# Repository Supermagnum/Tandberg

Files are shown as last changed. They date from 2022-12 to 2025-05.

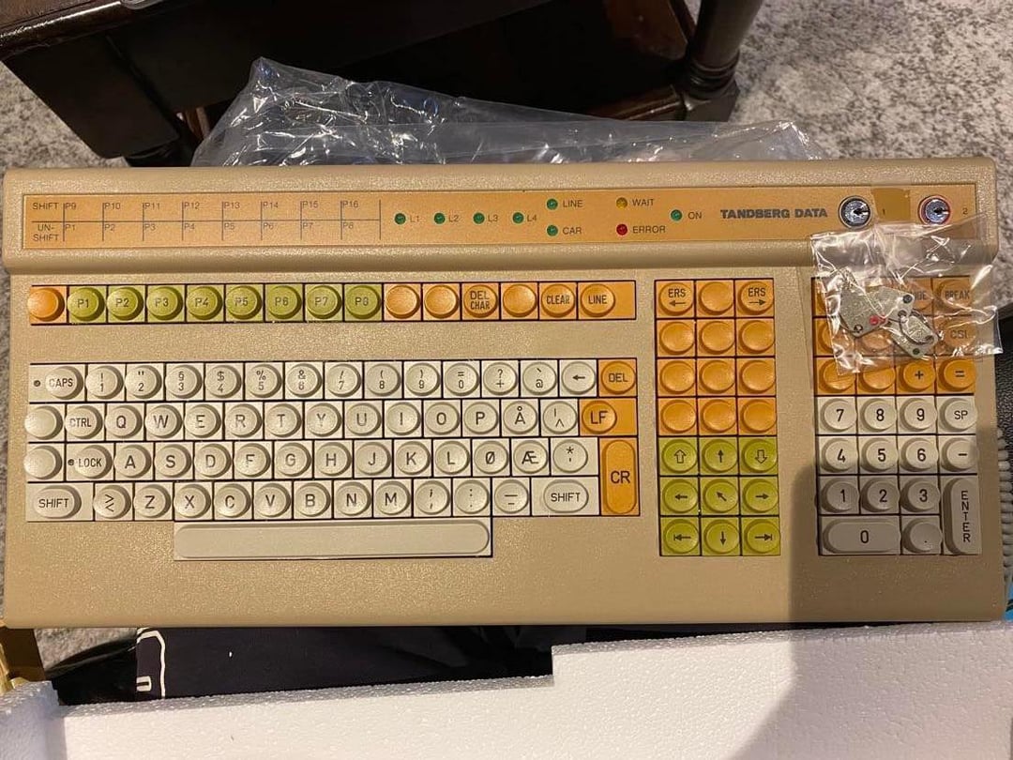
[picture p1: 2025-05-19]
a-tandberg-data-tdv2200-keyboard-picture-from-v0-ows3616kpe4a1-4209977600.jpg

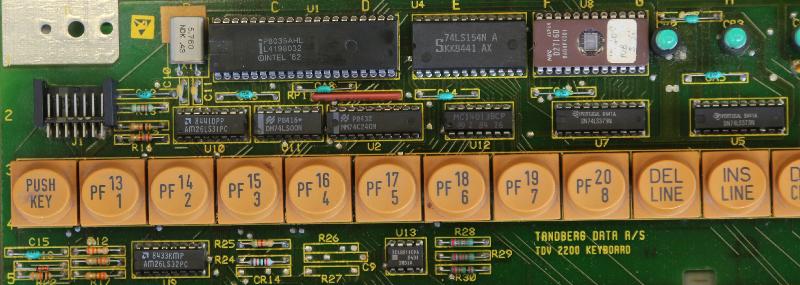
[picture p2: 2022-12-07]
TDV-2200/ROM-Files/TDV-2200 Keyboard Unk1/IMG_9250r.jpg

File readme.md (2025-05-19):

A repository for Tandberg Data Keyboards technical information an ROM's.

It was used for:
https://en.wikipedia.org/wiki/TDV_2200

Picture of a TDV 2200 keyboard:
https://raw.githubusercontent.com/Supermagnum/Tandberg/refs/heads/main/a-tandberg-data-tdv2200-keyboard-picture-from-v0-ows3616kpe4a1-4209977600.jpg

The keycaps looks like Devlin Z series.
https://www.devlin.co.uk/products/components/keycaps.html

They actually are Siemens STB 11/21.
The swtitches are described here:

Early models:
https://deskthority.net/wiki/Siemens_STB_11

Later:
https://deskthority.net/wiki/Siemens_STB_21

Tech details that I have been told: 
The keyboard runs standard UART over RS-485, 2400 baud from the keyboard and 600 baud to the keyboard. This is worth noting, as one does not always expect the speed of Rx and Tx to be different. Bytes sent from the keyboard are mostly pure ASCII codes when regular buttons are pressed.

Other keys have codes with bit 7 set to 1, often with the bottom 7 bits set to an equivalent ASCII code/function. Bytes you send to the keyboard are commands, like turning on/off "beep" at keystrokes, reading out key status, controlling the lights, and things like that.

What's available of commands varies slightly based on what firmware is in.

The biggest challenge is that, broadly speaking, the keyboard only sends characters when a button is pressed. Fine for typing, but not very much when one needs to press certain button combinations in Windows or Linux for example.

Source site:
https://sites.google.com/site/tingox/tdv2200

Adapter, it is for TDV2215 keyboard.
It also works for the 2200.
It should be possible to hack it to use a usb port.
https://github.com/Frodevan/Tandberg-Adapter

-----------------

TDV-5000 Series

A Quote from Frode van der Meeren:
Tandberg made these keyboards in the late 80s specifically for PC ports of Norsk-Data software (especially the NOTIS word processor). This was ten years before it was common to have a lot of extra buttons on the keyboard, so Tandberg naturally created his own system for these buttons. This system doesn't understand keyboard controllers on modern PCs (and certainly not drivers on modern operating systems), so the extra 20 buttons here are usually useless without a fix. The patch fixes this, and makes all the extra buttons output valid codes for "extra buttons" that have become standard in recent times.
The patch must be written to an 8051-compatible chip, but otherwise it is just a matter of replacing the controller that is in it with this one.

You can find the file here: https://github.com/Supermagnum/Tandberg/tree/TDV-5000/tdv_5000_patch.zip
You need an 8051 burner and an unprogrammed chip, but quite a few EPROM programmers handle this just fine.

Will only work with Tandberg-produced keyboards using Siemens-style switches (will NOT work with the later Cherry-OEM boards).

Relevant links:
https://deskthority.net/viewtopic.php?p=510471

https://deskthority.net/wiki/Tandberg_Data_TDV_5000_Series

-----------------
Controller Pcb measures: Generally:

* 51mm depth on the entire circuit board
* The width is not as critical, there is room for close to 400mm inside the rail in which it is mounted.

From the left edge of the circuit board, same side as the PS/2 connector:

* 11mm towards the right to the center of the PS/2 connector
* 57mm towards the right to the center of the first pin on the first flat cable
* 162mm towards the right to the center of the first pin on the second flat cable

Else
* 7mm downwards from the upper long side to the first pin on the flat cable
* 19mm length between the first and last pin on each flat cable (16 conductors, so approx. 1.24mm pitch).

Connectors:
LIF (Low Insertion Force) FFC socket. The pitch is 1.25mm

https://connectorbook.com/identification.html?m=NNK&n=ffc_fpc_lif_sockets&fl=000000000000-f-||1.25

* MANUF. - SERIES
* Adam Tech - PCB 1.25mm
* [JST](https://www.jst.com/products/ffc-fpc-connectors/fe-connector/) - [FE](https://www.jst.com/wp-content/uploads/2021/03/eFE.pdf) (pdf) - [digikey](https://www.digikey.ee/short/qz85mbb3)
* Molex - 52044 - [digikey](https://www.digikey.ee/short/bcqq5vn9)
* Molex - 52045 - [digikey](https://www.digikey.ee/short/rfdtp9t1)
* [TE](https://www.te.com/usa-en/products/connectors/pcb-connectors/wire-to-board-connectors/ffc-fpc-ribbon-connectors/fpc-connectors.html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) - 84533 - [digikey](https://www.digikey.ee/short/54bfrwrh)
* [TE](https://www.te.com/usa-en/products/connectors/pcb-connectors/wire-to-board-connectors/ffc-fpc-ribbon-connectors/fpc-connectors.html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) - 84534 - [digikey](https://www.digikey.ee/short/54bfrwrh)

Drop in PCB attempt, with modern controller and USB.
I hope that the footprints are OK.
https://github.com/Supermagnum/Tandberg/tree/main/Tandberg-USB

Suggested firmware that has to be written:
https://qmk.fm/

https://get.vial.today/

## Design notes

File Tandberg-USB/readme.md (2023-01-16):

CPU used:
https://github.com/yuWangWu/WeAct-Blackpill-STM32F411CEU6-QMK

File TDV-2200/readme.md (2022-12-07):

	Tandberg TDV-2200 Series Terminals

	This collection is ROMs from two complete Tandberg TDV-2200 class terminals, and three additional
	loose keyboard. The terminals in question is the TDV-2215, and ND320. The TDV-2215 is a general-
	purpose TDV-2200 ASCII-terminal, while the ND320 was a TDV-2200-9S terminal designed in particular
	for use with the Norsk Data ND-NOTIS suite of applications. NOTIS was a popular set of office-
	related applications running on Norsk Data NORD-100/NORD-500 mainframes, under the SINTRAN-III
	multi-user operating-system.

	The files follow a "label.part.designator" structure. The part is primarely for indicating pinout,
	and there may be slight variations on the actual boards. For example, an equalivent part with a
	different part-number might be used. The label-part is on the other hand written as accurately as
	possible, and will include revision or checkusm info where it is written on the actual labels.

	Keyboards runs an intel 8035, terminals runs an 8085. The two terminal-models are roughly the same,
	but the ND320 has a slightly enhanced motherboard over the TDV-2215, and a bitmap graphics-card
	expansion running its own Z80 and firmware. The first main difference in motherboard design between
	the two versions, is that the ND320 has a socket for a 27128 EPROM in addition to U31. Both of
	these sockets share the same chip-enable from the Address-Decoder. The second difference is that
	the ND320 has a whole lot more pages in the character-generator. Schematics and other documents for
	the TDV-2215 is available online at: http://sintran.com/sintran/library/libother/libother.html

							-Frode van der Meeren, "frodevan", 2020-04-20

	Keyboard IDs:

		(TDV-2215)	Keyboard, TDV 2200 Series, Item no.: 4024, Serial no.: 338705
		(TDV-2215)	Keyboard, TDV 2200 Series, Item no.: 4076, Serial no.: 376493
		(ND320)		Keyboard, TDV 2200S Series, Item no.: 4580, Serial no.: 682075
		(ND320)		Keyboard, TDV 2200S Series, Item no.: 4580, Serial no.: 707648

	Terminal IDs:

		(TDV-2215)	TDV 2200 Series, Basic Unit, TDV 2215, Serial no.: 302581
		(ND320)		TDV 2200S Series, Basic Unit, TDV 2200/9S, 1029789, 85. 

	ROMs:

		Keyboards

			961292 2.2716.u8		Item no. 4024, firmware
			961299 -3-.2716.u8		Item no. 4076, firmware
			965313 -0-.2716.u8		Item no. 4580, firmware
			xxxVT100S.u8			Siemens MTS 2000, firmware

		Basic Unit, TDV 2215

			961125.82S129.u27		Address Decoder
			961126.74S471.u67		Display Address Translation
			961127.82S131.u55		Attribute Lookup
			961133 0.2732.u63		Character Generator
			961264-10.2764.u31		Firmware 961755 Rev 11 part 1/3
			49032-2-11.2764.u32		Firmware 961755 Rev 11 part 2/3
			49032-11-3-.2716.u33		Firmware 961755 Rev 11 part 3/3

		Basic Unit, TDV 2200/9S

			961126 -0-.74S471.u67		Display Address Translation
			961127 -0-.82S131.u55		Attribute Lookup
			965190 -0-.82S129.u27		Address Decoder
			965115 -2-.27128.u63		Character Generator
			965090-24 -1-.27128.u93		Firmware 965090 Rev 23 part 1/2
			965094-24 -3-.2764.u32		Firmware 965090 Rev 23 part 2/2

			067141 92AF.2764.u61		Firmware TD720 Graphics Card 067 V1.4 part 1/2
			067142 229C.2764.u53		Firmware TD720 Graphics Card 067 V1.4 part 2/2

			U9 of the graphics card may be programmable, but unfortunately soldered down.

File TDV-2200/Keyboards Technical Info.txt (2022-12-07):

Communication:

	UART over RS-422
	8-bits per byte, no parity
	2400 baud Tx, 600 baud Rx

///////////////////////////////////////////////////////////////

Keyboard keynames:

	+----------------------------------------------------------------------------------------------------+
	|                                                                                                    |
	|                                                                                                    |
	|                                                                                                    |
	|  G0  G1  G2  G3  G4  G5  G6  G7  G8  G9  G10 G11 G12 G13 G14      G47 G48 G49 G50 G51 G52 G53 G54  |
	|                                                                   F47 F48 F49 F50 F51 F52 F53 F54  |
	|    E0  E1  E2  E3  E4  E5  E6  E7  E8  E9  E10 E11 E12 E13 E14    E47 E48 E49 E50 E51 E52 E53 E54  |
	|  D99 D0  D1  D2  D3  D4  D5  D6  D7  D8  D9  D10 D11 D12 D13      D47 D48 D49 D50 D51 D52 D53 D54  |
	|  C99  C0  C1  C2  C3  C4  C5  C6  C7  C8  C9  C10 C11 C12 C13     C47 C48 C49 C50 C51 C52 C53 C54  |
	|    B99   B0  B1  B2  B3  B4  B5  B6  B7  B8  B9  B10 B11          B47 B48 B49 B50 B51 B52 B53 B54  |
	|                                A5                                 A47 A48 A49 A50 A51     A53      |
	|                                                                                                    |
	+----------------------------------------------------------------------------------------------------+

Keynames in key datatable:

	Offset:
	00-0F	  x   x   x A50 A49 A48 A47 C49 D48 E48 B49 G50   x   x E50 C50
	10-1F	C54 B53 C53 B52 B51 B50 C51 D54 D51 E52 C52 E53 E54 D52 E51 D53
	20-2F	F50 F49 F53 F52 F51 F54 G54 G53 D49 F48 G52 G48 F47 E49 G49 G51
	30-3F	 B0  B1  B2  B3  B4  B5  B6  B7  B8  B9 B10 A51  A5 B48 B47 C13
	40-4F	 C1  C2  C3  C4  C5  C6  C7  C8  C9 C10 C11 B54 C48 C47 C99 C12
	50-5F	 D1  D2  D3  D4  D5  D6  D7  D8  D9 D10 D11 D50 D47 D99 D13 D12
	60-6F	 E1  E2  E3  E4  E5  E6  E7  E8  E9 E10 E11 A53 E47 E14 E13 E12
	70-7F	 G0  G1  G2  G3  G4  G5  G6  G7  G8  G9 G10 G47 G14 G13 G12 G11

Key datatables in layout definition:

	Offset:
	000-07F		Key flags
	080-0FF		Normal Key-values
	100-17F		Shift held Key-values
	180-1FF		Ctrl held Key-values

///////////////////////////////////////////////////////////////

	Commands sent to Keyboard

///////////////////////////////////////////////////////////////

	00	Do nothing
	01-08	Turn LED 1-8 on
	09-10	Turn LED 1-8 off
	11-18	Turn LED 1-8 on in RAM bitmap only
	19-1F	Do nothing
	20-2F	Excecute operation 1-16
	30	Set bit 2 of P2 (2200S models only)
	31-FF	Do nothing

Operations:

	1	Do Nothing
	2	Enable Click
	3	Disable Click
	4	Turn on CAPS
	5	Trigger Beeper
	6	Turn off LED 1 to 8
	7	Turn off LED 1 to 4
	8	Check Keyboard Expansion busy state (DATA line. returns EF if 0, F5 if 1)
	9	Enable Key-Repeat
	10	Disable Key-Repeat
	11	Read Locks
	12	Disable READY to expansion
	13	Enable READY to expansion
	14	ROM Check (AA = ok, else fail)
	15	RAM Check (AA = ok, EE = fail)
	16	Read Selected Layout ID number (6 chars)

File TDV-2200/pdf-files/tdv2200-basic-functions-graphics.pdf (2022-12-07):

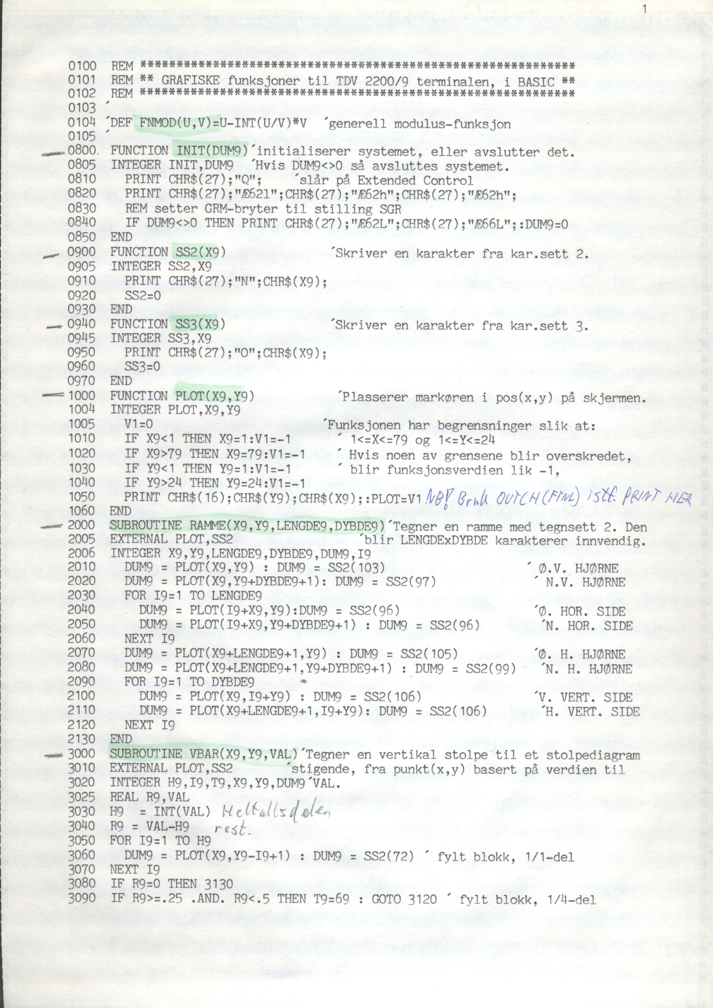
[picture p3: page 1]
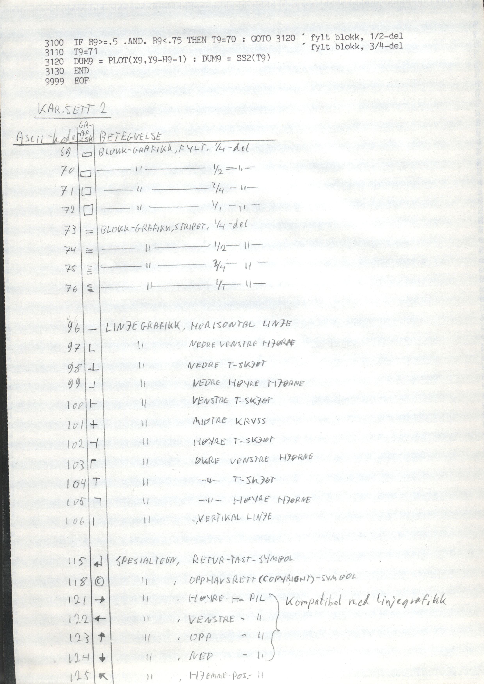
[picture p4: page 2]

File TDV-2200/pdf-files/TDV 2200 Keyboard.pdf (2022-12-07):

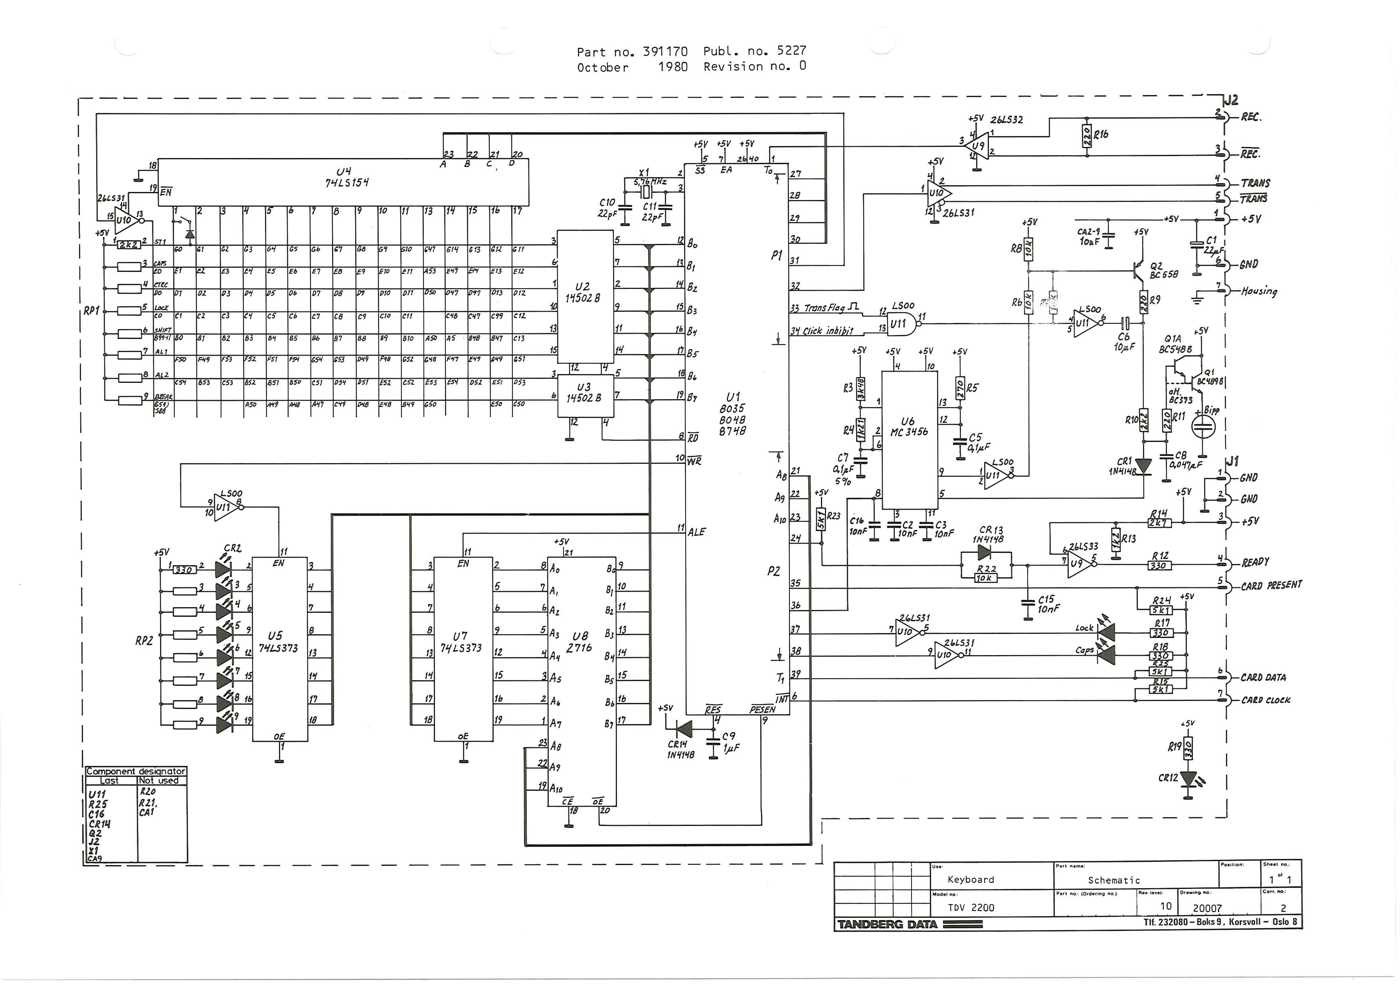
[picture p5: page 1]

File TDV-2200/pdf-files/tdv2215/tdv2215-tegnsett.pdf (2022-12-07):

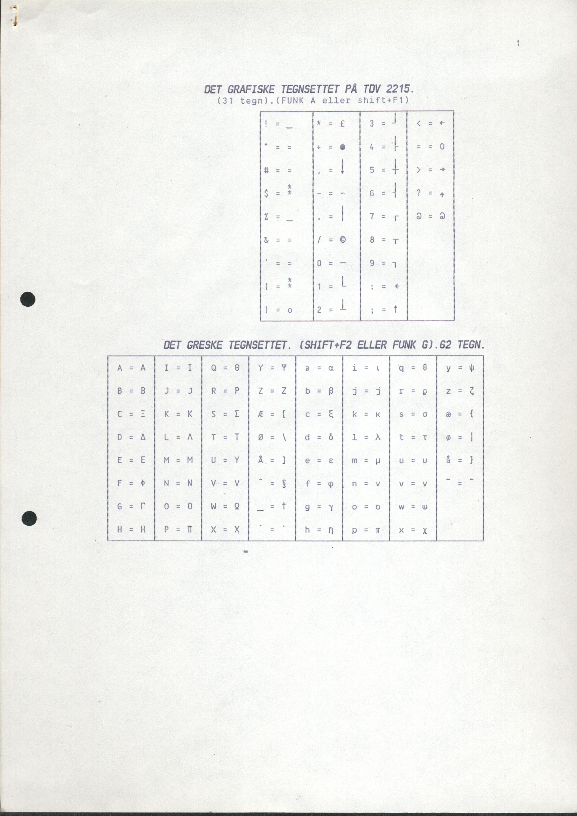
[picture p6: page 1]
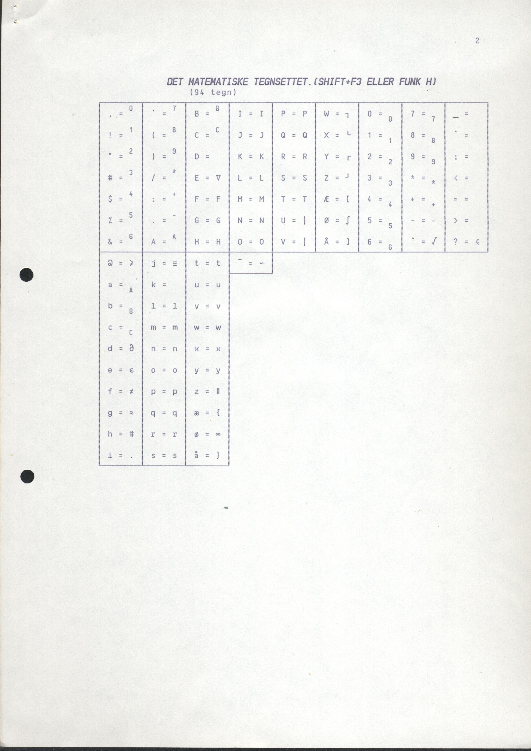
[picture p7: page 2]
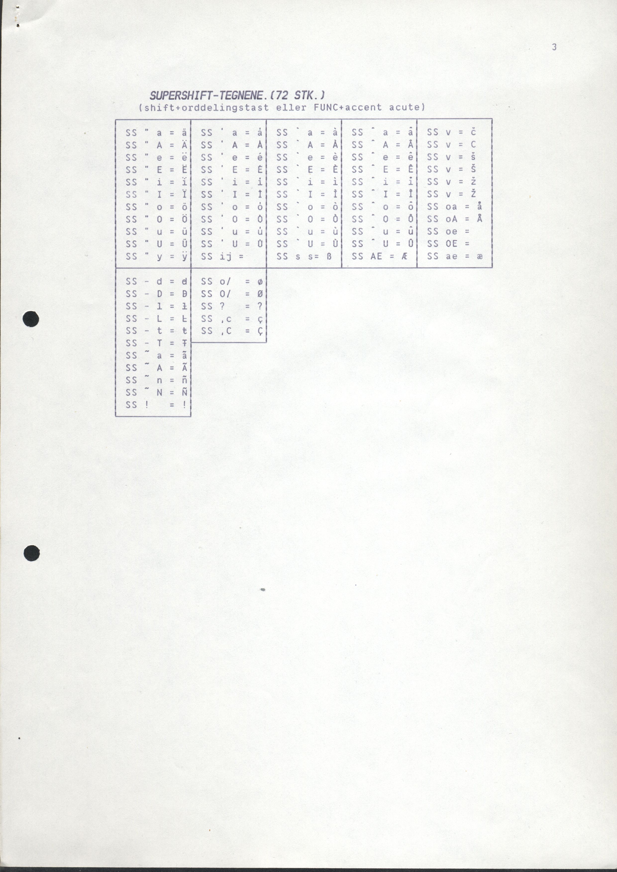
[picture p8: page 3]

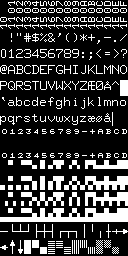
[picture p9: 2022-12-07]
TDV-2200/ROM-Files/TDV-2200 Base Unit TDV-2215/Font 961133 0 Inv.bmp

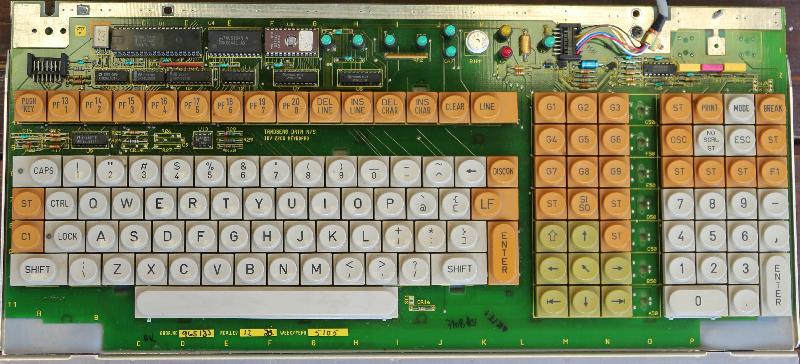
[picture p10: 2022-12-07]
TDV-2200/ROM-Files/TDV-2200 Keyboard Unk1/IMG_9251r.jpg

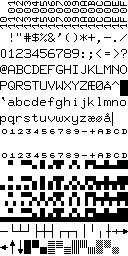
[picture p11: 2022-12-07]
TDV-2200/ROM-Files/TDV-2200 Base Unit TDV-2215/Font 961133 0.bmp

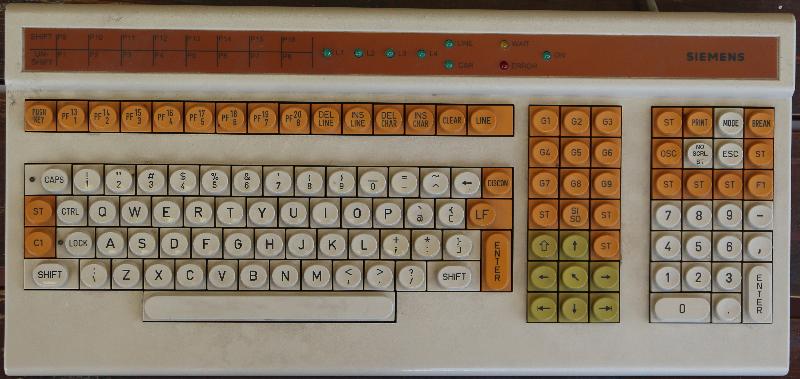
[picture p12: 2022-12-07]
TDV-2200/ROM-Files/TDV-2200 Keyboard Unk1/IMG_9252r.jpg

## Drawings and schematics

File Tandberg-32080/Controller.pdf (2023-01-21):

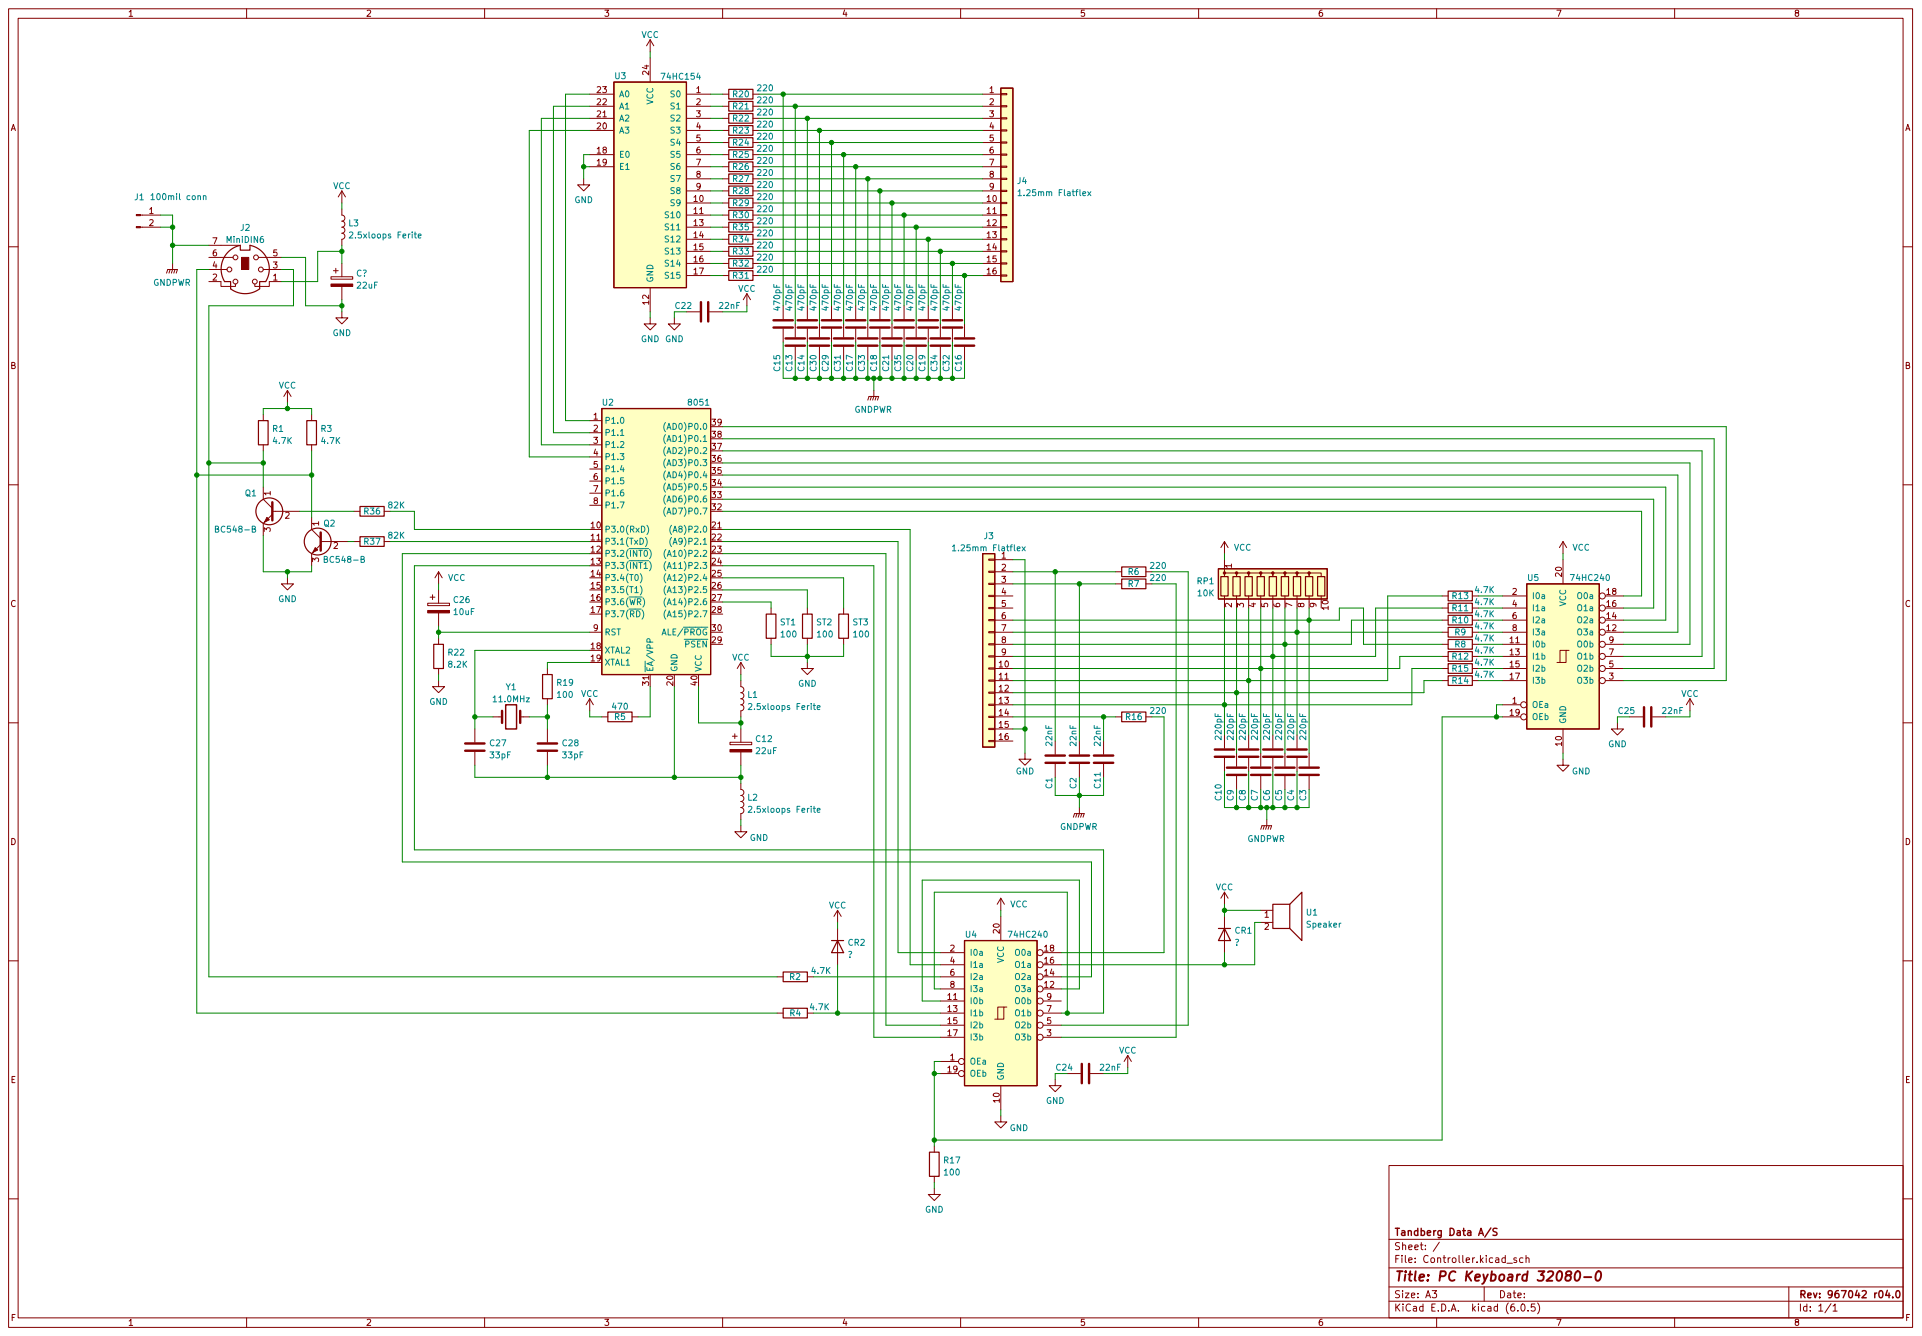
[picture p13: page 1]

10
11
12
13
14 15

File: Controller.kicad_sch Sheet: / Tandberg Data A/S

Id: 1/1 Title: PC Keyboard 32080-0

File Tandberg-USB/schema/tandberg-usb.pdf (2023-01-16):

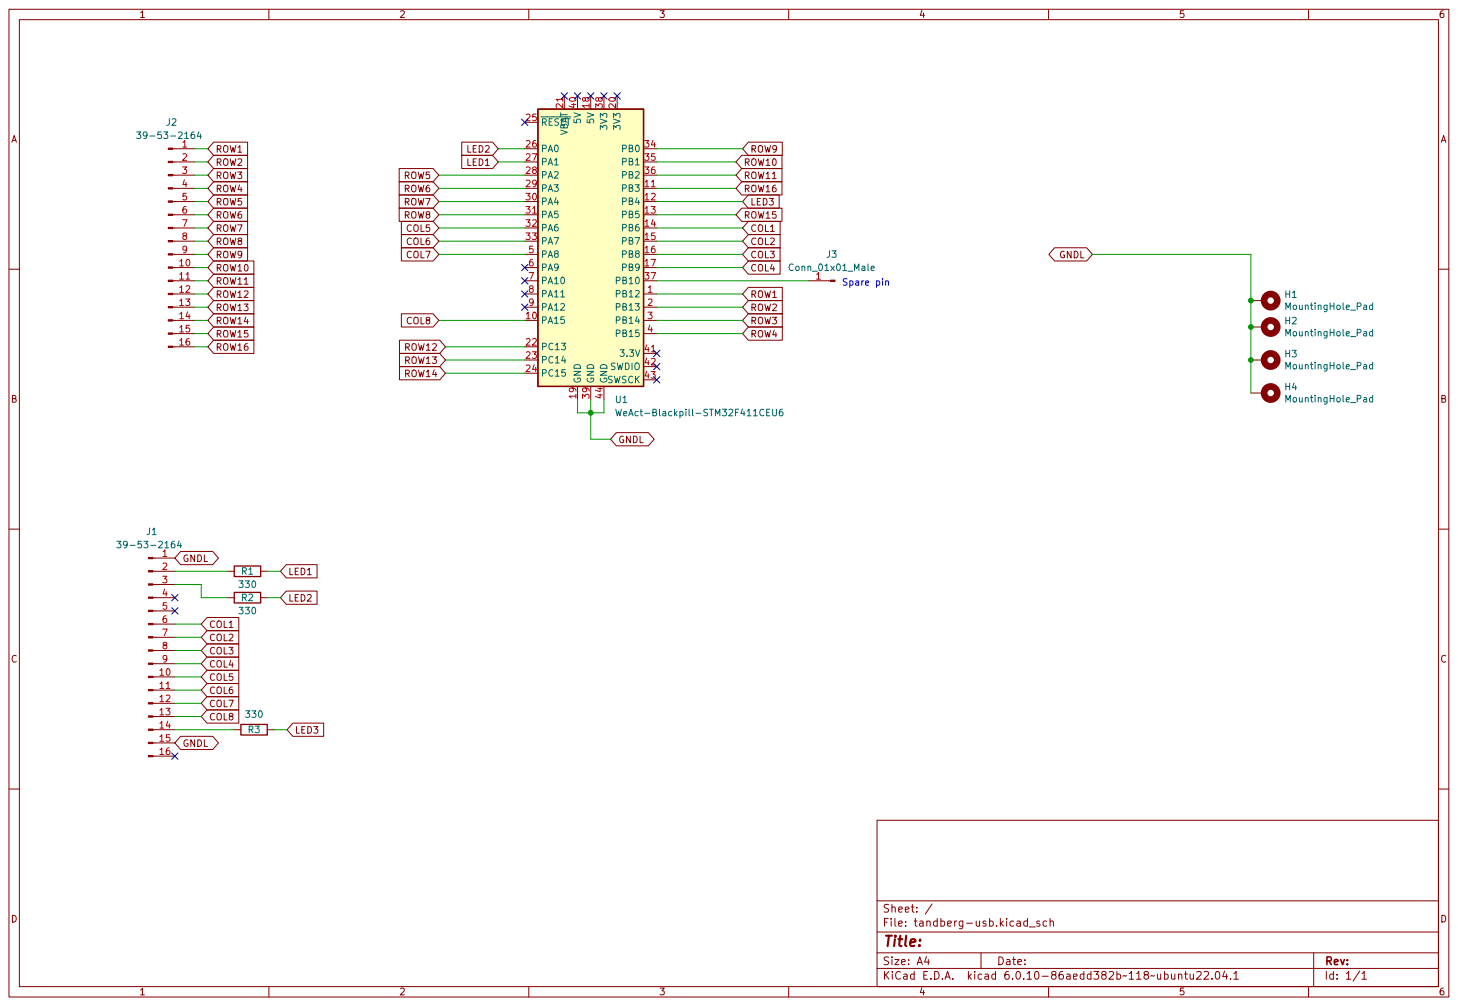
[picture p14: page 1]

File: tandberg-usb.kicad_sch Sheet: /
Id: 1/1 Title:

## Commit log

2022-12-07 Update readme.md
    Added switch info
2023-01-13 Organization, added files for TDV-5000
    [keymap.xlsx]
2023-01-15 More layout info for TDV-5000, matrix map, scancode table is now a textfile
    [keymap.xlsx]
2023-01-15 A attempt at creating a new controller
    A attempt at creating a new controller board for TDV 2200 series,- It has two Rasperry picos, uses I2C communication.
    The reason for two MCU's are because one alone does not have enough pins.
    [tandberg-5000-B_Cu.gbr, tandberg-5000-B_Mask.gbr, tandberg-5000-B_Paste.gbr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]
